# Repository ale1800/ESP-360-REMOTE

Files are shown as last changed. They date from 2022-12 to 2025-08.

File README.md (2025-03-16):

# ESP-360-REMOTE
## An all-in-one remote based on the ESP32-WROOM-32E

- ## ~~ESP 360 Remote on [CrowdSupply](https://www.crowdsupply.com/aaelectronics/esp-360-remote)~~ (Out of stock)
- ## If you want, you can build it by yourself. Productions files are [here](https://github.com/ale1800/ESP-360-REMOTE/tree/main/Hardware/Production)

- ## ESP 360 Remote on [Discord](https://discord.gg/PsrK3KDkRy)

This board boasts a RF transmitter and receiver, while IR LEDs are arranged in a circle to provide omnidirectional coverage. Additionally, it comes equipped with a temperature and humidity sensor, as well as an ambient light sensor. To top it off, the board can be powered and programmed through a USB Type-C port, which is ESD protected. Based on the ESP32-WROOM-32E, this board can be effortlessly configured with ESPHome, allowing for seamless control via Home Assistant.
You can swap the 433MHz modules with 315MHz ones because the SRX/STX882 modules come in both version with the same pinout, so you can choose which one fit your needs the best

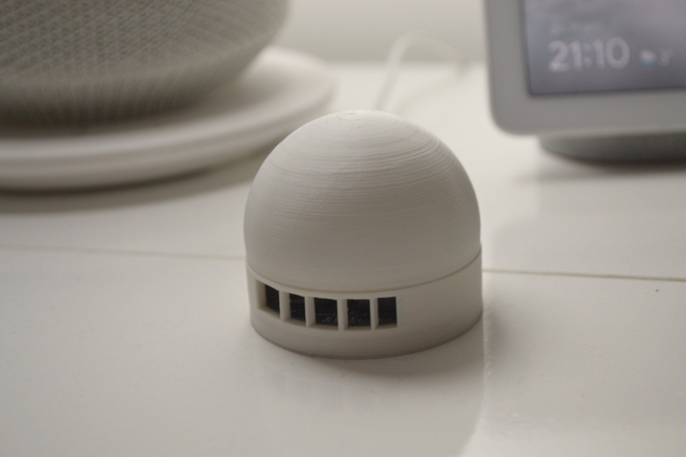
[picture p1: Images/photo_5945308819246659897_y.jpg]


I think the form factor it's nice because there are two round stackable layers. 

The first layer of the board includes the ESP32, the two sensors, the buck converter and the USB circuitry.

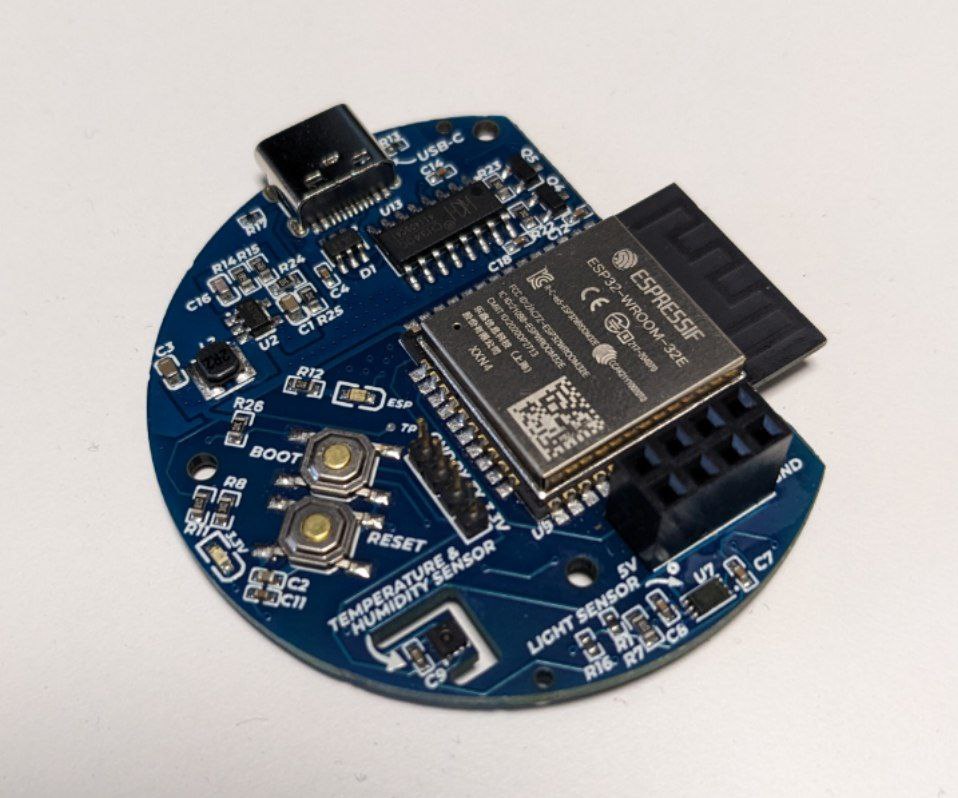
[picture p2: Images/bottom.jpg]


The second layer of the board features the IR leds and receiver and the RF modules.

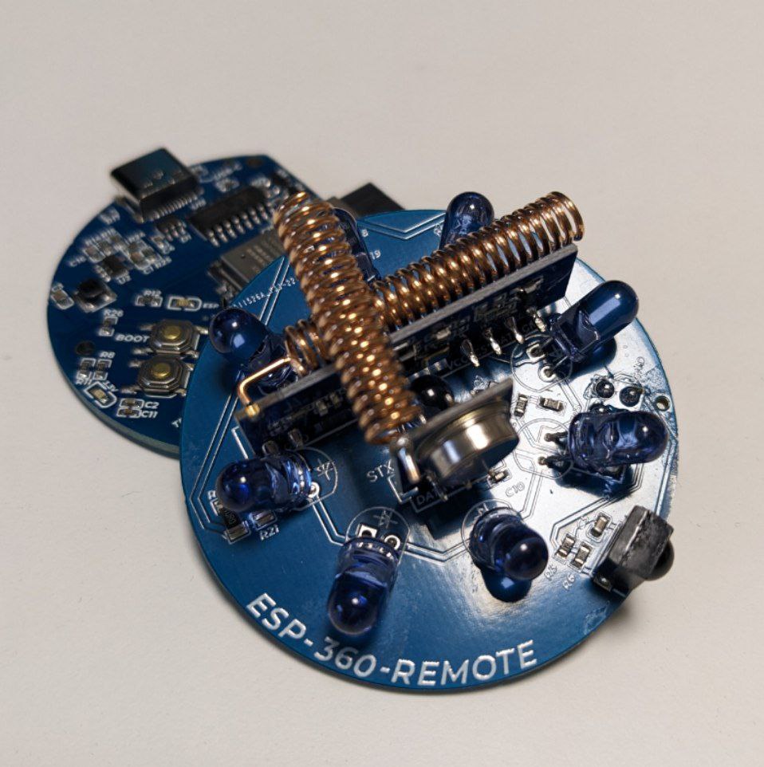
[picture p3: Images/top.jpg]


Inside the enclosure just stack the two layers using the x8 female header near the ESP:

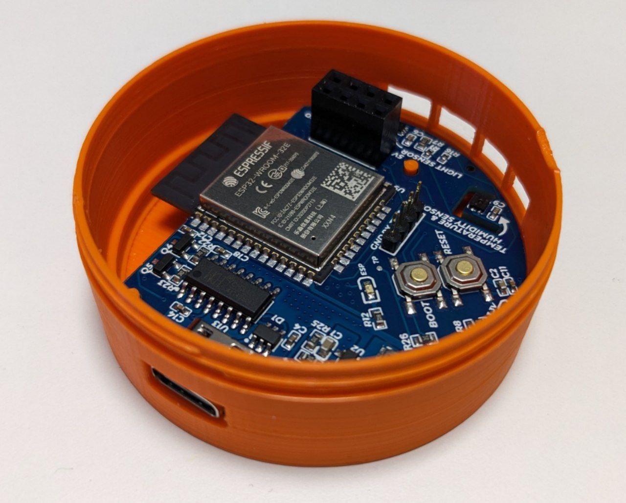
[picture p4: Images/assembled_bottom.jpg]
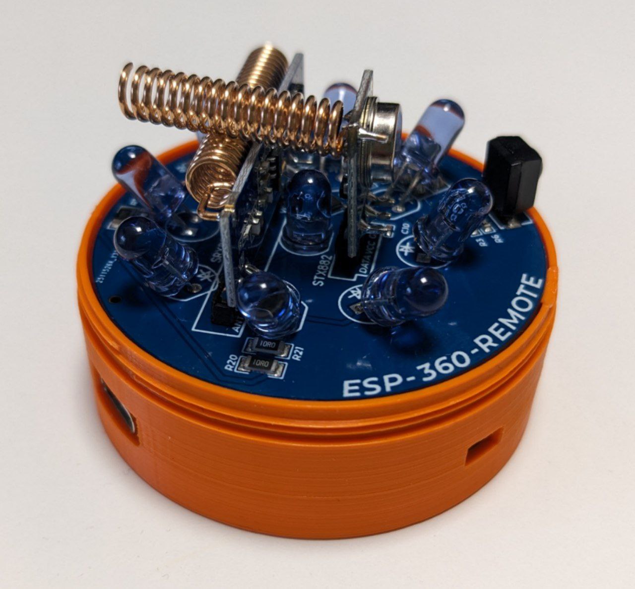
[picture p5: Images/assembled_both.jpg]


Then screw the top part and turn the board on!

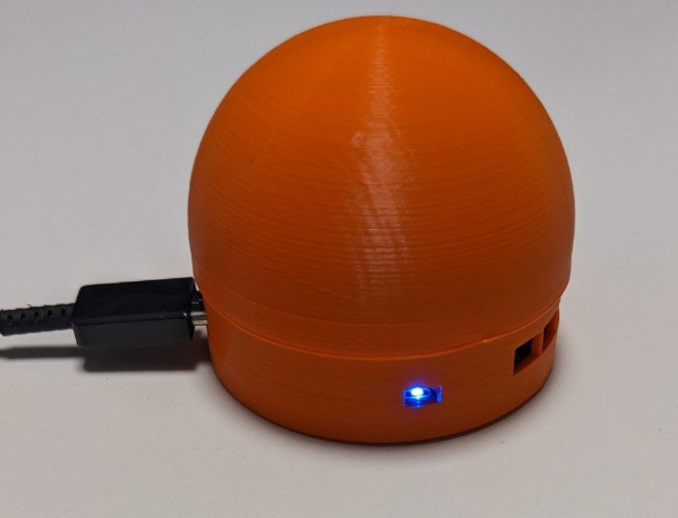
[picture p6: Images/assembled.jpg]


Now you can also program the board with the USB-C. I suggest to use ESPHOME beacuse it's super easy to setup and to integrate with Home Assistant

# Installation
Once you receive the ESP 360 Remote, if you don't have a running server of Home Assistant, you will need to follow the instructions in [INSTALL.md](INSTALL.md) to use the board as a "standalone" product, otherwise just follow the [quick start guide](https://github.com/ale1800/ESP-360-REMOTE/blob/main/Quick%20start%20guide.md).

# Home Assistant Integration

ESP 360 REMOTE is designed to be fully integrated into Home Assistant and leverage the capabilities provided by ESPHome. If you decide to use the configuration file provided in this repo, you will see these exposed entities:

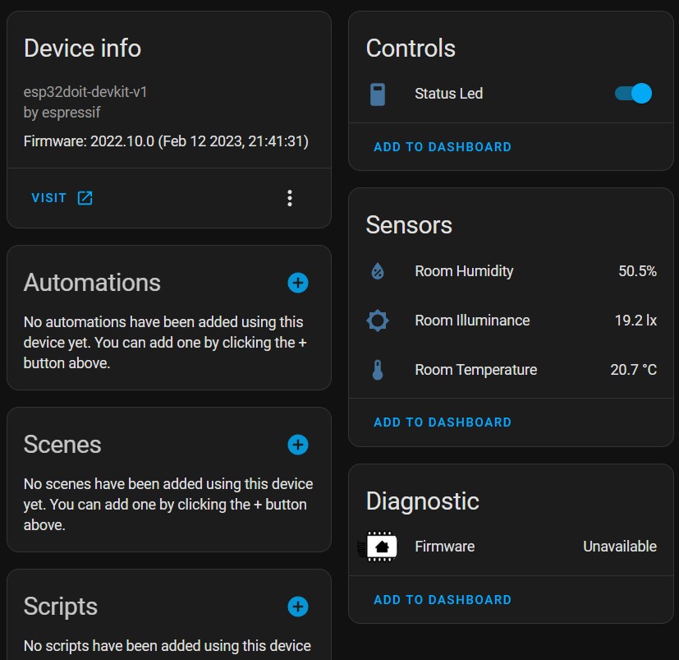
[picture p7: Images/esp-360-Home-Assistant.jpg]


## Transmitting signals

Thanks to the ease of use of ESPHome, you can create custom switches or integrate existing components (see https://esphome.io/components/climate/climate_ir.html) by directly modifying the yaml file, and all of this will be immediately visible on Home Assistant. Alternatively, if you want to take an even simpler route, you can use two integrated services to send raw IR and RF signals:

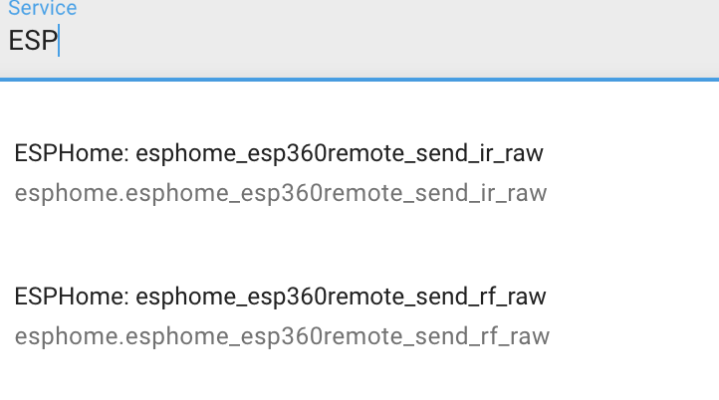
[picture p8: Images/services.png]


This way you won't need to tinker with the ESPHome configuration and you'll be able to send signals directly from your automations!

## Receiving signals

When the board receives an RF signal, the **esphome.rf_code_received** event will be triggered in Home Assistant. From there, you can directly see the protocol and code of the received signal. The same feature will soon be available for the infrared receiver as well.

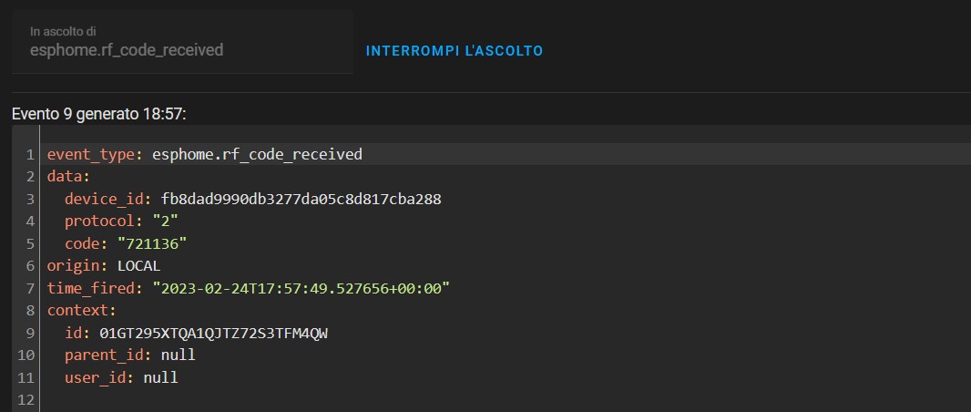
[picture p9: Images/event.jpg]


In this case, I received the code 721136 (10110000000011110000 in binary) and protocol 2

## SmartIR Integration

ESPHome ensures compatibility with the widely-used SmartIR custom component for Home Assistant, thanks to its built-in support for transmitting raw signals. If you already have a SmartIR configuration in place, all you need to do is specify the appropriate service for transmitting signals and a code that is compatible with ESPHome. Here's an example of what your configuration.yaml file could look like:

```
smartir:

climate:
  - platform: smartir
    name: Livingroom AC
    unique_id: livingroom_ac
    device_code: 7065
    controller_data: esp360remote_send_ir_raw
    temperature_sensor: sensor.living_room_temperature
```
For more information, check out the [SmartIR repo](https://github.com/smartHomeHub/SmartIR).

# Dimensions

The board is remarkably compact, measuring just 5cm in diameter and 3.5cm in height without the enclosure. This small form factor makes it a perfect fit for any space. To put its size into perspective, it's smaller than the Broadlink RM3 Mini, which is the only device I have available for comparison.

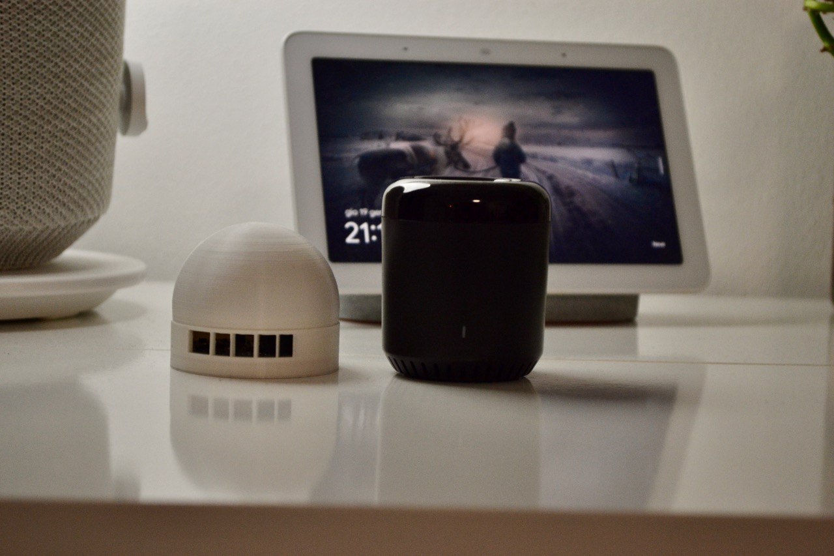
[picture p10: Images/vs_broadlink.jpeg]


# Enclosure

Within this repository, you can also access the two STL files for the enclosure, which enables you to print it in your preferred color to match its intended location. The pre-designed enclosure includes openings near the USB-C port and two built-in sensors to optimize airflow and cool down the temperature sensor. The top part of the enclosure can be screwed on, so there's no need for additional screws or components. I've only tested printing with light-colored PLA, and the IR transmission was not impacted at all. However, I can't make any claims about other materials or dark colors.

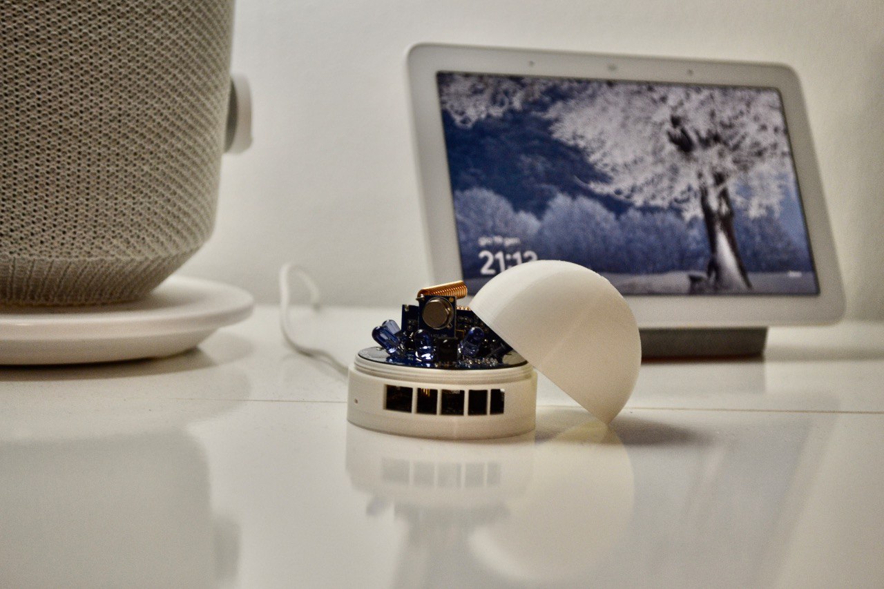
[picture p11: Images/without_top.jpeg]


# OSHWA Certification
In the end, the project also has the OSHWA certification with UID IT000012, so it's completely open source!

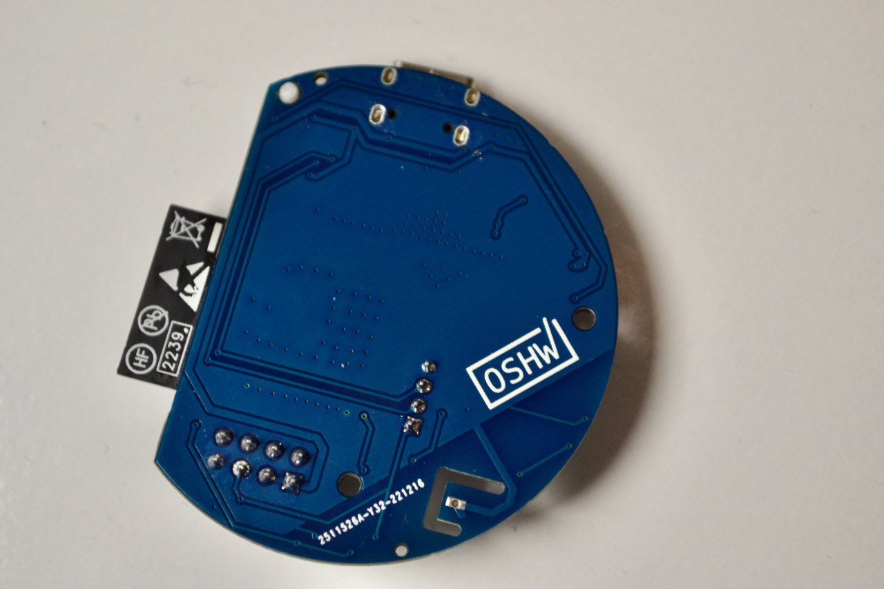
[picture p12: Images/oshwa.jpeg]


License:

oshw_facts

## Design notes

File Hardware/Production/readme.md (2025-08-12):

 I suggest you to buy also the right angle pin strips I soldered on the RF modules.
 
 - I used [these](https://www.lcsc.com/product-detail/_XFCN-_C781823.html) for the 3-pin transmitter module ([STX883Pro](https://www.nicerf.com/ask-modules/ask-transmitter-module-stx883pro.html)). 
 They have the standard pitch of 2.54 but they are thin enough to be inserted in the female connector on the board  **You have to buy at least 4 (2x2)** and then cut one. 
 
 - For the receiver module ([SRX883Pro](https://www.nicerf.com/ask-modules/ask-receiver-module-srx883pro.html)), pins are [these](https://www.lcsc.com/product-detail/_HCTL-_C2905972.html). Also with these you have to cut one (I connected it to the board only with 5 pins out 6)

Pay attention if you need the RF modules in 433MHz or 315MHz version. And then buy the spring antenna accordingly, like [these ones](https://www.lcsc.com/products/Antennas_912.html).

If you let the manufacturer assemble the board, remember to ask them to bend the IR leds to 45°, otherwise they will solder them straight.

You can flash your ESP 360 Remote directly from [here](https://aaelectronics-docs.com/documentation/flashing/flashing.html) using a chromium-base browser

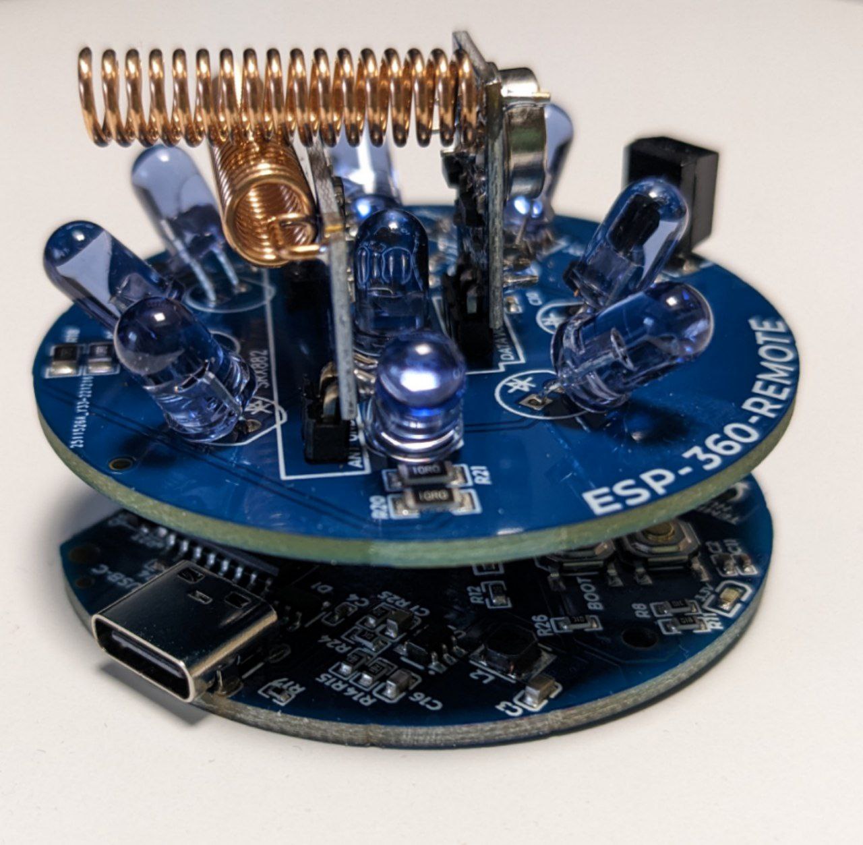
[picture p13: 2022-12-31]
Images/both.jpg

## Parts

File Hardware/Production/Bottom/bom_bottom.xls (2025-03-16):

Comment | Designator | Footprint | JLCPCB Part #
ESP32-WROOM-32E(8MB) | U9 | WIFI-SMD_ESP32-WROOM-32E | C701342
TS-KG001T | BOOT | SW-SMD_L6.0-W3.5-P9.0 | C410369
TYPE-C-31-M-12 | USBC1 | USB-C_SMD-TYPE-C-31-M-12 | C165948
10uF | C2 | C0402 | C15525
MT3410LB | U2 | TSOT-23-5_L2.9-W1.6-P0.95-LS2.8-BR | C883494
SM04B-SRSS-TB(LF)(SN) | CN2 | CONN-SMD_4P-P1.00_SM04B-SRSS-TB-LF-SN | C160404
5.1kΩ | R1,R13,R16,R17 | R0402 | C25905
BH1750FVI-TR | U7 | WSOF-6_L2.6-W1.6-P0.50-TL-EP | C78960
USBLC6-2SC6 | D1 | SOT-23-6_L2.9-W1.6-P0.95-LS2.8-BR | C7519
22uF | C1,C3 | C0603 | C59461
19-217/BHC-ZL1M2RY/3T | 3.3V | LED0603-R-RD_BLUE | C72041
220S-2*4PH=8.5MMYtypeGold-plated | H1 | HDR-TH_8P-P2.54-V-F-R2-C4-S2.54-1 | C124422
10kΩ | R8,R22,R23,R24,R25,R26 | R0603 | C25804
100nF | C12,C4,C7,C8,C9,C11,C14,C18 | C0402 | C307331
1kΩ | R7,R11 | R0603 | C21190
22pF | C16 | C0603 | C1653
CH340C | U13 | SOP-16_L10.0-W3.9-P1.27-LS6.0-BL | C84681
180kΩ | R14,R15 | R0603 | C22827
SS8050_C2150 | Q4,Q5 | SOT-23-3_L2.9-W1.3-P1.90-LS2.4-BR | C2150
2.2uH | L2 | IND-SMD_L3.0-W3.0 | C354563
SHTC3-10000 | U3 | DFN-4_L2.0-W2.0-P1.00-BL-EP | C2880044

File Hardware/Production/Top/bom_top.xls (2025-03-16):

Comment | topDesignator | bottomDesignator | Footprint | JLCPCB Part #
HDR-TH_5P-P2.00-V-F | H3 |  | HDR-TH_5P-P2.00-V-F | C2935969
DY-IR333-A | U1,U5,U6,U14,U16,U17,U18,U19,U20 |  | LED-TH_BD5.9-P2.54-FD | C95407
IRM-3638T | IR1 |  | OPTO-TH_IRM-3638T | C16216
HDR-TH_3P-P2.54-V-F-3 | U4 |  | HDR-TH_3P-P2.54-V-F-3 | C2844843
10Ω | R2,R9,R18,R19,R20,R21 |  | R1206 | C17903
220Ω | R3,R4 |  | R0603 | C22962
10kΩ | R6,R5 |  | R0603 | C25804
100nF | C6,C10 |  | C0402 | C307331
PZ254V-12-8P |  | H2 | HDR-TH_8P-P2.54-V-M-R2-C4-S2.54 | C492421
AO3400A | Q1 |  | SOT-23-3_L2.9-W1.6-P1.90-LS2.8-BR | C20917
10uF | C5 |  | C0603 | C19702

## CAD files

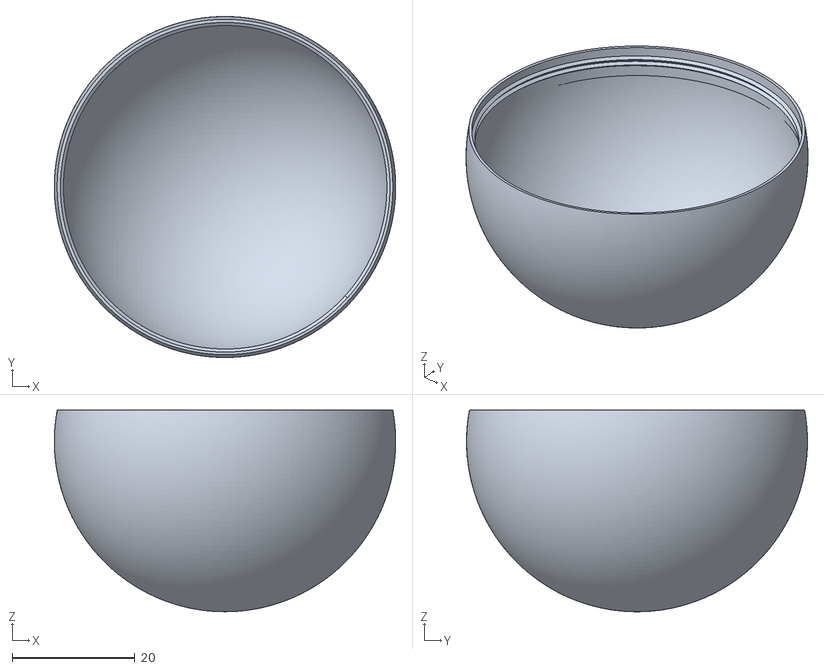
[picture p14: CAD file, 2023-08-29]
Enclosure/esp360remote-TOP.stl
55.7 x 55.7 x 32.9

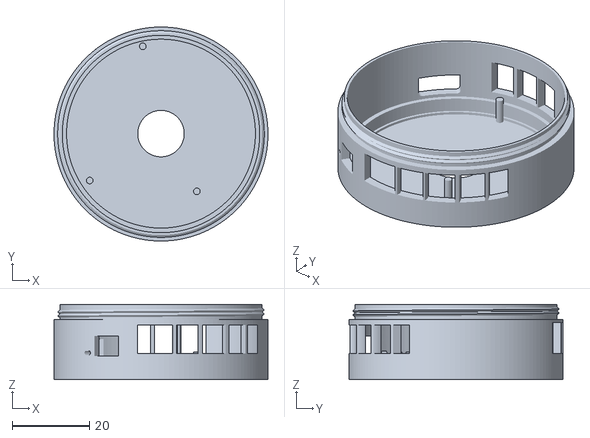
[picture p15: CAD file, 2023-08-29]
Enclosure/esp360remote-YES_I2C-BOTTOM.stl
55.3 x 55.3 x 19.4

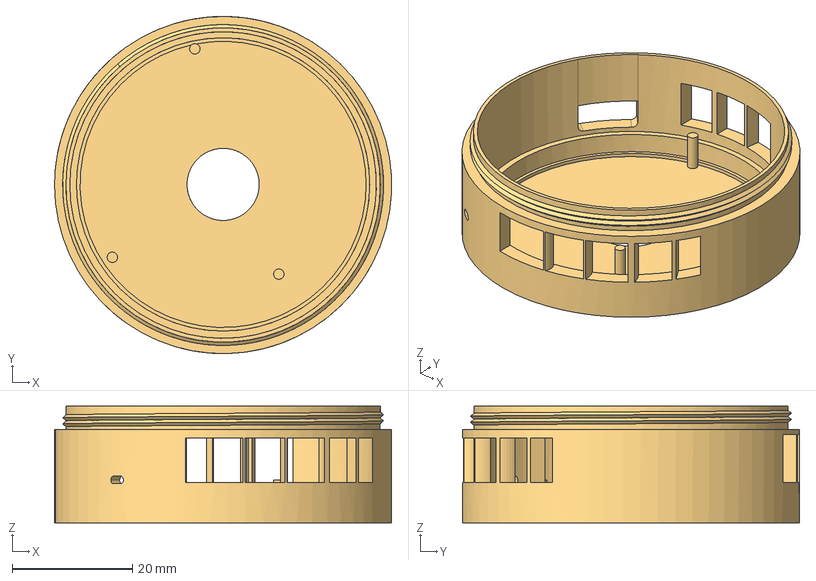
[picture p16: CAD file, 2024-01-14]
Enclosure/Original files/bottom.step
56.1 x 56.1 x 19.4 mm

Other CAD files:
Enclosure/Original files/top.step
Enclosure/Original files/bottom_I2C.step
Enclosure/esp360remote-TOPs.step
Enclosure/esp360remote-NO_I2C_BOTTOM.stl
Enclosure/esp360remote-TOP-PLA.stl

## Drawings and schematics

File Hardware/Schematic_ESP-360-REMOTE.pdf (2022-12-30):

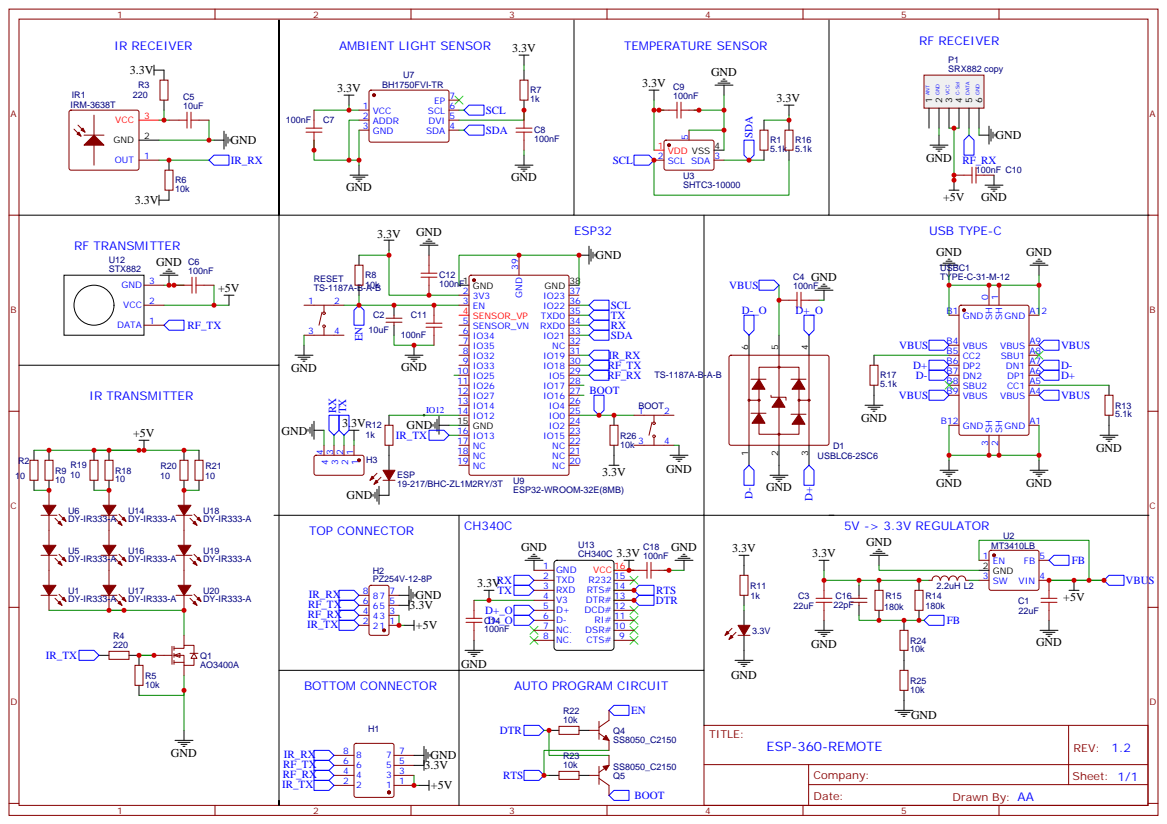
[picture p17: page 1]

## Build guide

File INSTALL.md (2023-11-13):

# Introduction

To start, follow the [quick start guide](https://github.com/ale1800/ESP-360-REMOTE/blob/main/Quick%20start%20guide.md) just for the installation part.

If you know ESPHome, you can skip most of this document and just use the template in the [ESPHome Configuration](https://github.com/ale1800/ESP-360-REMOTE/tree/main/ESPHome%20Configuration) folder.

If you don't know much about ESPHome this document will guide you through the installation process. If you need more information you can head to [Discord](https://discord.gg/PsrK3KDkRy) and if you see something that is not clear enough, do not hesitate to make a pull request and improve the documentation for everybody.

# First step
For this step you will require a USB-C cable that has power + data (a normal cable should but some cheap aliexpress cable only have the power wire and no data wire) and a computer with chrome or edge browser (no firefox)
open the following [link](https://web.esphome.io/) in your browser once the device is connected to your computer using the USB-C cable
you need to click on "connect".



Select the USB-Serial device, if no USB serial device appear, ensure your USB cable is good and that you have the CH240X driver (the tool give you the link to install the driver if needed)



Once you are connected you should be able to click there : 



The process takes a few minutes and ask for your wifi credentials toward the end so that the device can connect to your network.
once it's done you should be able to access the webpage hosted by the ESP 360 Remote



As you can see it's empty. this is only the generic ESPHome configuration. follow to the next section to compile the firmware with the IR, RF and sensors feature

Now, if you want to change the yaml file and update your ESP 360 Remote directly from the command line, you can jump to the **Command Line** section, otherwise if you would like to manage your board from an intuitive web page, go to the **ESPHome Environment** one. 

# Command Line
First follow this guide that will help you install the compiler for the ESPhome firmware.
[ESPHome tool desktop installation](https://esphome.io/guides/installing_esphome.html).
Now you can use the templates in the **Template** section and follow this guide (under the **First uploading section**) to compile the template provided here for your device :
[ESPHome tool desktop usage](https://esphome.io/guides/getting_started_command_line).
You can now jump to the **Template** section

# ESPHome Environment
This option require docker but allow you to manage in an easier way your fleet of esphome device



I assume you know the docker basics, here is a docker-compose.yml that you can use to run the ESPhome "fleet manager"
```
version: '3'
services:
  esphome:
    container_name: esphome
    image: ghcr.io/esphome/esphome
    volumes:
      - /path/to/esphome/config:/config
      - /etc/localtime:/etc/localtime:ro
    restart: always
    privileged: true
    network_mode: host
    environment:
      - USERNAME=test
      - PASSWORD=ChangeMe
```

Edit the username + password and the path to your configuration (just an empty folder is good, we will create the file from the web interface)

Once it's running you can can access it on http://127.0.0.1:6052/
From there you can create a new device



Once done, click on skip for the install and click "edit" instead from the main menu : 

Remlace the text with the one found in the [ESPHome Configuration](https://github.com/ale1800/ESP-360-REMOTE/tree/main/ESPHome%20Configuration) folder.
as explained in the template section of this file
once happy with your config you can compile by clicking save then come back to the main menu and click the "..." then install



Choose manual download



The file will be compiled to a .bin that you will be able to download. you need to download the legacy format :





From there, give it a name and choose ESP32



Now return to the webpage of the ESP 360 Remote and under OTA Update browse for the file you previously downloaded and click update
once the device as rebooted, you should see the value from the sensors and your switch



you are done :)

# Template

Here is what the template looks like. you can edit the name field and the wifi ssid + password with your
```
esphome:
  name: esp360-default-1
  friendly_name: ESP360-default-1

esp32:
  board: esp32dev
  framework:
    type: arduino

# Enable logging
logger:

api:
  encryption:
    ...
```
You can add your own action.
This is an example that send an IR code that turn ON and OFF a fan.
You will need to adapt the transmit_nec function to your protocol and replace the address and command field accordingly
```
  - platform: template
    name: "fan"
    turn_on_action:
      remote_transmitter.transmit_nec:
        transmitter_id: IR_TX
        address: 0xFE01
        command: 0xE21D
    turn_off_action:
      remote_transmitter.transmit_nec:
        transmitter_id: IR_TX
        address: 0xFE01
        command: 0xE21D
```
If you dont know theses, you can start by compilling the base template and go to the webpage of the ESP 360 remote, you should see a terminal that display the data from the sensors and the IR + RF transceiver
just point the remote you want to clone toward the ESP 360  remote and look at the code display in the terminal.
It should looks like something like this :



The line that we care about is the following
```
Received NEC: address=0xFE01, command=0xE21D
```
This line give you the protocol (NEC) the address and the command. if you have another protocol lookup in the ESPhome documentation the specific syntax.

Edit the example template with your value and add as many as you need for every function of your remote you want to clone and use from the ESP 360 Remote.

(dont hesitate to read the ESPhome documentation as it will give you more detailed info and more options to configure your actions)

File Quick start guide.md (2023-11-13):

# QUICK START GUIDE FOR THE ESP 360 REMOTE

## INSTALLATION

**Step 1**: Insert the base of the ESP 360 Remote into the case and make sure that all the openings align, as well as the 3 holes in the PCB with the 3 plastic pins.

.

**Step 2**: Insert the RF modules into the upper part of the PCB as shown in the picture and manually raise the infrared LEDs to a 45° angle. They are currently bent horizontally for transportation safety reasons.

.

**Step 3**: Insert the top PCB all the way into the base through the 8-pin connector.

.

**Step 4**: Close the case by screwing the top part, plug in the power cable, and wait for the board’s hotspot called Esp360Remote or Esp360Remote2 (if you ordered the teo pack) to appear!

.

## CONNECTION TO HOME ASSISTANT

**Step 1**: When the fallback hotspot is available, connect to it with Esp360Remote as password (for both of the AP’s name)

.

**Step 2**: After connecting to its hotspot, go to ip: 192.168.4.1 on your web browser, connect to your WiFi and you are done! Home Assistant should have now discovered your Esp 360 Remote!

.

**Step 3**: Now you can go to the ESPHome dahsboard on your Home Assistant instance and create a new project clicking on the bottom-right "+" icon. Choose the name you want.

.

**Step 4**: Now click on "skip this step" and then select the ESP32 in the next window.


.

**Step 5**: Now it will appear your new encryption key. You can save it somewhere and use it to modify the one in the default template, then click "SKIP".

.

**Step 6**: At this point, you should have your new project in the dashboard. Then click "EDIT", remove everything inside and copy and paste the [default configuration](https://github.com/ale1800/ESP-360-REMOTE/blob/main/ESPHome%20Configuration/esp360-default-1.yaml). Use both the yaml files if have two boards. Then you can change the encryption key if with the one you saved before and **be sure to change the WiFi settings with your credentials**, otherwise it will create again its own hotspot. After you've done that, you can click "SAVE", then "INSTALL" and select "WIRELESSLY". If you've done everything correctly, you should be see your device online in the dashboard and should be able to modify their configuration!


.

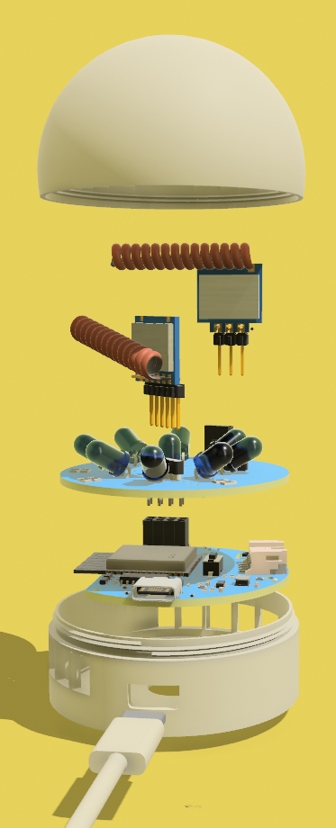
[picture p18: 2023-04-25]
Images/website/esp360remote-disassembled.png

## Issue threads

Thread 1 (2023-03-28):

Bottom enclosure thickness

jimt, 2023-03-28:
When I tried to have JLPCB 3D print the enclosure in 9000R resin, they complained that the bottom piece wall thickness was too thin.  They suggested it be at least 0.8mm, or even better 1.5mm.

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

commit:  dfe3e82

ale1800, 2023-03-28:
Hello, thanks for writing me! They told me the same, but make them print it
anyway, It will work👍

Il mar 28 mar 2023, 06:18 Jim Tittsler ***@***.***> ha
scritto:

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

Closed 2023-04-10.

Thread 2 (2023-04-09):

RF Events not triggering

gid204, 2023-04-09:
Before I buy one of these awesome products I decided to slap a DIY version together to confirm I can get my devices working as required before spending the money (I have most parts readily available).

I am not able to receive any RF codes using the home assistant event developer tool. Just wanted to check I am not doing anything wrong.

```yaml
substitutions:
  name: "esp-remote"
  room: "Lounge"
  friendly_name: "ESP Remote"
  project_name: "kaneo.esp_remote"
  project_version: "0.0.1"

esphome:
  name: "${name}"
  name_add_mac_suffix: false
  friendly_name: "${friendly_name}"
  project:
    name: "${project_name}"
    version: "${project_version}"

esp32:
  board: esp32dev

logger:

api:

  services:
    - service: send_rf_raw
      variables:
        protocol_number: int
        raw_data: string
      then:
        - remote_transmitter.transmit_rc_switch_raw:
            transmitter_id: RF_TX
            protocol: !lambda 'return  esphome::remote_base::RC_SWITCH_PROTOCOLS[protocol_number];'
            code: !lambda 'return raw_data;'

ota:

web_server:

ethernet:
  type: LAN8720
  mdc_pin: GPIO23
  mdio_pin: GPIO18
  clk_mode: GPIO17_OUT
  phy_addr: 0
  power_pin: GPIO12
  domain: ".lan"

remote_receiver:
  - id: RF_RX
    pin:
      number: GPIO5
      inverted: True
    dump:
      - rc_switch
    tolerance: 35%
    filter: 200us
    idle: 4ms
    buffer_size: 10kb
    on_rc_switch:
      - homeassistant.event:
          event: esphome.rf_code_received
          data:
            protocol: !lambda 'return x.protocol;'
            code: !lambda 'return x.code;'

#Setting up IR and RF transmitters
remote_transmitter:
  - id: RF_TX
    pin: GPIO14
    carrier_duty_percent: 100%
```

Everything is connected up as per the config above.
I then go the developer tool events section and listen for `esphome.rf_code_received`:
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

I point my blinds RF (433MHz) remote and click some buttons but nothing pops up.

Obviously can't attest for the quality but these are the receivers/transmitters I bought and am using:
https://www.aliexpress.com/item/32735811163.html?spm=a2g0o.new_account_index.0.0.286725b9MZf6XG

I am using the Climax ESP32 POE board:
https://www.olimex.com/Products/IoT/ESP32/ESP32-POE/open-source-hardware

Thanks in advance!!

ale1800, 2023-04-09:
Hello! Everything seems fine to me.
There could be some things to modify, like tolerance, filter and idle.

One thing to try is to dump everything instead just rc_switch. Do that and let me know👍

gid204, 2023-04-10:
Thanks for the tip - after setting dump to 'all' I can now seem my codes coming through, they appear to be in 'pronto' format.
My new yaml (I changed to wifi just for an easier setup while debugging):
```yaml
substitutions:
  name: "esp-remote"
  room: "Lounge"
  friendly_name: "ESP Remote"
  project_name: "kaneo.esp_remote"
  project_version: "0.0.1"

esphome:
  name: "${name}"
  name_add_mac_suffix: false
  friendly_name: "${friendly_name}"
  project:
    name: "${project_name}"
    version: "${project_version}"

esp32:
  board: esp32dev

logger:

api:

  services:
    - service: send_rf_raw
      variables:
        # protocol_number: int
        raw_data: string
      then:
        - remote_transmitter.transmit_rc_switch_raw:
            transmitter_id: RF_TX
            # protocol: !lambda 'return  esphome::remote_base::RC_SWITCH_PROTOCOLS[protocol_number];'
            code: !lambda 'return raw_data;'

ota:

web_server:

wifi:
  ssid: !secret wifi_ssid
  password: !secret wifi_password

  domain: ".lan"
  # Enable fallback hotspot (captive portal) in case wifi connection fails
  ap:
    ssid: "ESP-Remote Fallback Hotspot"
    password: "K2I4dMrvo3RA"

captive_portal:

# ethernet:
#   type: LAN8720
#   mdc_pin: GPIO23
#   mdio_pin: GPIO18
#   clk_mode: GPIO17_OUT
#   phy_addr: 0
#   power_pin: GPIO12
#   domain: ".lan"

remote_receiver:
  - id: RF_RX
    pin:
      number: GPIO5
      inverted: True
    dump:
      - pronto
    tolerance: 35%
    filter: 200us
    idle: 4ms
    buffer_size: 10kb
    on_pronto:
      - homeassistant.event:
          event: esphome.rf_code_received
          data:
            # protocol: !lambda 'return x.pronto_protocol;'
            code: !lambda 'return x.data;'

#Setting up IR and RF transmitters
remote_transmitter:
  - id: RF_TX
    pin: GPIO14
    carrier_duty_percent: 100%
```

It looks like [pronto](https://esphome.io/api/structesphome_1_1remote__base_1_1_pronto_data.html) struct doesn't have a 'protocol' data field as [rc_switch](https://esphome.io/api/structesphome_1_1remote__base_1_1_r_c_switch_data.html) does. It only expects a string. However, there is a separate [pronto_protocol](https://esphome.io/api/classesphome_1_1remote__base_1_1_pronto_protocol.html) class, but I'm not too sure if this is needed to be implemented in anyway?

So I am now receiving my codes:
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

But when I try send this data using the transmitter nothing happens:
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

I have confirmed that all formatting from the raw code is removed.

I am quite knew to the rf_transmitter/receiver components (if that wasn't already obvious) so once again you're help is really appreciated!

ale1800, 2023-04-10:
Great, so some progress.
Once you receive the pronto data, you should be able to transmit it with this action **remote_transmitter.transmit_pronto**
So add this service and try to transmit with it.

```yaml
    - service: send_rf_pronto
      variables:
        pronto_data: string
      then:
        - remote_transmitter.transmit_pronto:
            transmitter_id: RF_TX
            data: !lambda 'return pronto_data;'
```

gid204, 2023-04-11:
Unfortunately sending the pronto code isn't getting my RF device (blind motor) to respond. I can see that my transmitter is working though as when I transmit the code, my esphome receiver picks it up in the logs.

I do notice that it seems to send a few pronto codes as separate 'transmissions', perhaps this is needed to operate my device.

I also came across this [thread](https://community.home-assistant.io/t/esp32-ir-remote-pronto-inconsistent-data-not-sending/504681).

I'm not sure if this also applies to RF as they are discussing IR?

I may have to go down that rabbit hole to see if I can get mine working with raw commands.

ale1800, 2023-04-11:
Oh ok. Quite sure, that thread applies also to RF. So you can try what they say there. Also press a lot of times the button on the original remote and try to emulate the one that appears more often.

And are you sure the receiver only recognizes pronto protocol? Maybe you can use some other protocols which are easier to use

Closed 2023-08-09.

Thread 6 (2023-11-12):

https://ale1800.github.io/ESP-360-REMOTE/ broken link

stappersg, 2023-11-12:
subject says all

stappersg, 2023-11-12:
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

is where I found the (currently) broken link.

stappersg, 2023-11-12:
And a closer look:
```text
$ wget --server-response https://ale1800.github.io/ESP-360-REMOTE/
--2023-11-12 23:29:21--  https://ale1800.github.io/ESP-360-REMOTE/
Resolving ale1800.github.io (ale1800.github.io)... 185.199.111.153, 185.199.110.153, 185.199.108.153, ...
Connecting to ale1800.github.io (ale1800.github.io)|185.199.111.153|:443... connected.
HTTP request sent, awaiting response...
  HTTP/1.1 301 Moved Permanently
  Connection: keep-alive
  Content-Length: 162
  Server: GitHub.com
  Content-Type: text/html
  permissions-policy: interest-cohort=()
  Location: http://esp360remote.io/ESP-360-REMOTE/
  X-GitHub-Request-Id: 8B8C:B4BD:30D7FFF:31BB8B7:655151C1
  Accept-Ranges: bytes
  Date: Sun, 12 Nov 2023 22:29:22 GMT
  Via: 1.1 varnish
  Age: 0
  X-Served-By: cache-ams21043-AMS
  X-Cache: MISS
  X-Cache-Hits: 0
  X-Timer: S1699828162.009825,VS0,VE107
  Vary: Accept-Encoding
  X-Fastly-Request-ID: 5e8f0769abc7630d2dd3c47b8442a2dd10b2e971
Location: http://esp360remote.io/ESP-360-REMOTE/ [following]
--2023-11-12 23:29:22--  http://esp360remote.io/ESP-360-REMOTE/
Resolving esp360remote.io (esp360remote.io)... failed: Name or service not known.
wget: unable to resolve host address 'esp360remote.io'
$
```

ale1800, 2023-11-13:
Yes, thank you. It was an old link. I removed it

Closed 2023-11-13.

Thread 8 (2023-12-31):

Print Setting?

LostInIgnorance, 2023-12-31:
Can you add the print settings you are using to the STL file folder please

ale1800, 2024-01-13:
Hello, sorry for my late response. I don't know if you still need it. However what I use for the bottom part is:

No support
Infill: 20%
Line Width: 0.44 mm
Layer height: 0.2 mm

For the top part you can add supports for the highest point of the dome

If you need some particular parameter, please ask me

ale1800, 2024-01-14:
@LostInIgnorance I used shapr3d to design the enclosure. I can share the step files or even the "native" ones if you use the same program

ale1800, 2024-01-14:
@LostInIgnorance I uploaded [here](https://github.com/ale1800/ESP-360-REMOTE/tree/main/Enclosure/Original%20files) everything

LostInIgnorance, 2024-01-14:
I don't have shapr3d and I am not sure how to modify the same base, but with a wall mount option (just a couple of screw holes on a bracket/extended wall). The USB C cord I am using is below so I don't need much space in the back for the USB C connection.

https://www.amazon.com/gp/product/B0CCJRWKC5

Closed 2024-02-11.

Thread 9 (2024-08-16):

IR Receiver events

Haves1001, 2024-08-16:
Hi, I would like to primarily use the device for receiving signals from my IR remote control.
I've been reading in the documentation that "The same feature will soon be available for the infrared receiver as well." - now my question, is that feature already available for IR events?

ale1800, 2024-08-16:
Hello! Sure, it will work. If you missed it, have a look here: https://www.crowdsupply.com/aaelectronics/esp-360-remote/updates/a-deep-dive-into-automation

Closed 2024-12-09.

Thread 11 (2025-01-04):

Minor issues in configuration files

aancel, 2025-01-04:
Hello,

First thanks for the great device and tutorials !
I recently reworked my configuration and had issues with the setup, so I worked on an "in-my-own-words" document for setting up ESP-360-REMOTE from scratch (See: https://github.com/aancel/admin/wiki/ESP%E2%80%90360%E2%80%90REMOTE if this can help anyone)

Regarding the current documentation and the issues I encountered, here are a few suggestions if you'd like to update them:
- I first started to have issues with this part of the yaml configuration files:

```
ota:
  password: ""
```

It seems that recent ESPHome updates required it to be updated to:

```
ota:
  platform: esphome
  password: ""
```
for the configuration to be applicable.

- Following this, I would suggest to set a version to the container used in [Install.md](https://github.com/ale1800/ESP-360-REMOTE/blob/main/INSTALL.md) instead of using the default (latest). I, for example, used 2024.12.2. This would make the setup more robust regarding api changes in the future.

- One last thing, that does not seems to cause issues at least for now, is that the `api.services` seems to have been renamed to `api.actions` (see https://esphome.io/components/api.html)

And that should be about it. As previously said, feel free to close this issue, if you'd prefer to keep it as is.
Hopefully this can help other people using ESP-360-Remote.

Thanks,

ale1800, 2025-01-05:
Hi! Thank you very much for your time.
You are absolutely right. At the time, when I programmed the whole stock I wasn't aware of the possibility to import and adopt a device from the ESPHome dashboard. The whole procedure could have been much more simple.
In addition, with ESPHome updates, some part of the code needed some changes, like the "ota" one you mentioned before.
So, thanks again for your effort. I'm going to link the document in the repo so it will be easier to read!

Closed 2025-02-12.

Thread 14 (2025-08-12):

Soder past on U3 and U9

asucrews, 2025-08-12:
Hello, great device!

 I missed the pre-fab run, so I’m trying to get it made with PCBWay. They are asking if U3 and U9 need solder paste for the ground pads under the chips

I want to be safe and ask, because I think it should since it to GND.

Closed 2025-08-12.

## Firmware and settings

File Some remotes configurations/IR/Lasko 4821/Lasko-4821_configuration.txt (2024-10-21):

# This provides IR buttons for controlling a Lasko fan.
# 
# I think Lasko may use the same codes for different meanings, so your mileage may vary on the button names.
#
# I used the same technique documented at https://ryfow.com/articles/esp-360-remote-rc300/ to find these codes.
# The tricky part was figuring out that carrier_frequency: 38000 is required. I eventually guessed my way into that.

remote_receiver:
  - id: IR_RX
    pin: 
      number: GPIO19
      inverted: true
    idle: 100ms
    dump: raw

remote_transmitter:
  - id: IR_TX
    pin: GPIO13
    carrier_duty_percent: 50%

button:
  - platform: template
    name: "Fan Power"
    on_press:
      remote_transmitter.transmit_raw:
        code: [1313, -383, 1312, -382, 460, -1234, 1313,  -382, 1312, -382, 460, -1235, 466, -1229, 460, -1234, 462, -1233, 462, -1232, 461, -1233, 1314]
        carrier_frequency: 38000
        repeat:
          times: 10
          wait_time: 7200us
        transmitter_id: IR_TX
  - platform: template
    name: "Fan Speed"
    on_press:
      remote_transmitter.transmit_raw:
        code: [1282, -414, 1307, -387, 454, -1240, 1306, -389, 1279, -415, 454, -1240, 431, -1263, 456, -1238, 432, -1262, 457, -1238, 1308, -387, 430]
        carrier_frequency: 38000
        repeat:
          times: 10
          wait_time: 8000us
        transmitter_id: IR_TX

  - platform: template
    name: "Fan Timer"
    on_press:
      remote_transmitter.transmit_raw:
        code: [1325, -372, 1320, -374, 471, -1223, 1322, -372, 1325, -370, 471, -1223, 471, -1223, 472, -1222, 1323, -373, 471, -1222, 471, -1223, 470]
        carrier_frequency: 38000
        repeat:
          times: 10
          wait_time: 8000us
        transmitter_id: IR_TX

  - platform: template
    name: "Fan Ion"
    on_press:
      remote_transmitter.transmit_raw:
        code: [1325, -372, 1325, -369, 472, -1221, 1327, -369, 1324, -370, 474, -1219, 1326, -370, 473, -1221, 472, -1222, 499, -1195, 476, -1121, 572, -2133, 172]
        carrier_frequency: 38000
        repeat:
          times: 10
          wait_time: 8000us
        transmitter_id: IR_TX

  - platform: template
    name: "Fan Oscillate"
    on_press:
      remote_transmitter.transmit_raw:
        code: [1315, -382, 1313, -381, 462, -1231, 1314, -382, 1314, -380, 464, -1229, 465, -1230, 1287, -409, 463, -1230, 464, -1230, 466, -1229, 464]
        carrier_frequency: 38000
        repeat:
          times: 10
          wait_time: 8000us
        transmitter_id: IR_TX

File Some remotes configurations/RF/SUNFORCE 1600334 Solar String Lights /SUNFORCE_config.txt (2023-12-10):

switch:
  - platform: template
    name: "$upper_devicename Patio Lights Power Button p1"
    turn_on_action:
      - remote_transmitter.transmit_rc_switch_raw:
          transmitter_id: RF_TX
          code: '10101010111111111110100'
          protocol: 1
          repeat:
            times: 5
            wait_time: 1ms

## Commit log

2022-12-10 Create de
2023-01-27 Readme modified with enclosure and dimension
2023-01-27 Added enclosre stl
    [esp360remote-BOTTOM.stl, esp360remote-TOP.stl]
2023-03-04 Update esphome-esp360remote.yaml
    Light sensor is now calibrated
2023-04-01 Add files via upload
    Added step files
    [esp360remote-BOTTOM.step, esp360remote-TOP.step]
2023-09-24 Add files via upload
    Suggested for 3D Print at home with PLA
    [esp360remote-TOP-PLA.stl]
2023-11-11 Create INSTALL.md
    added basic info to configure the device in standalone mode and using the docker server
2023-11-20 Update and rename test.txt to RC-300_configuration.txt
    [RC-300_configuration.txt]
2024-01-14 Add files via upload
    Added original enclosure files
    [bottom.step, bottom_I2C.step, top.step]
2024-10-21 Add example IR buttons for a Lasko fan
    [Lasko-4821_configuration.txt]
